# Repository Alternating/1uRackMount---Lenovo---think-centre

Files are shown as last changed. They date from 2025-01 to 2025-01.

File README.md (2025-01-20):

# 1uRackMount - m720q - any tiny think centre

This is a 1U rackmount for Lenovo Tiny USFF computers (specifically m720q). 
- Modded for the use with sliding rails

Original creator - https://www.thingiverse.com/thing:4769452

Hardware Required
- https://www.cigarhumidors-online.com/cigar-accessories/miscellaneous-smoking-accessories/1u-sliding-server-rack-shelf.html <-- buy to acquire sliding rails
- m4 heat serts - 4mm x 4mm L x 6mm OD
- m3 heat serts - 3mm x 4mm L x 5mm OD
- m4 x 6mm - [Flathead socket cap]
- m3 [Flange lock nuts] 
- m3 x 0.5mm [hex nuts]
- m3 x 8mm [button head]
- m3 x 20mm [socket head]
- m4 x 20mm [button head]
- m4 x 10mm [socket head]
- m4 x 30mm [socket head]
- m4 x 50mm [button head]

Hardware Locations->: 

- 4x m4 [heatserts] - |-> Front
- 4x m4 30mm [socket head] - |-> Front
- 2x m4 [heatserts] - |-> Right Side
- 2x m4 6mm [FlatHead SocketCap] - |-> Right Side
- 2x m4 [heatserts] - |-> Left Side
- 2x m4 6mm [FlatHead SocketCap] - |-> Left Side
- 4x m3 20mm [sockethead] - |-> Rear Cap
- 3x m3 8mm [button head] - |-> connect left/right with extension
- 6x m3 [Flange lock nuts] - |-> connect left/right with extension
- 2x m3 8mm [button head] - |-> connect left/right with extension
- 2x m3 [hexnut] - |-> connect left/right with extension

- HDD: 8x m3 8mm [button head]

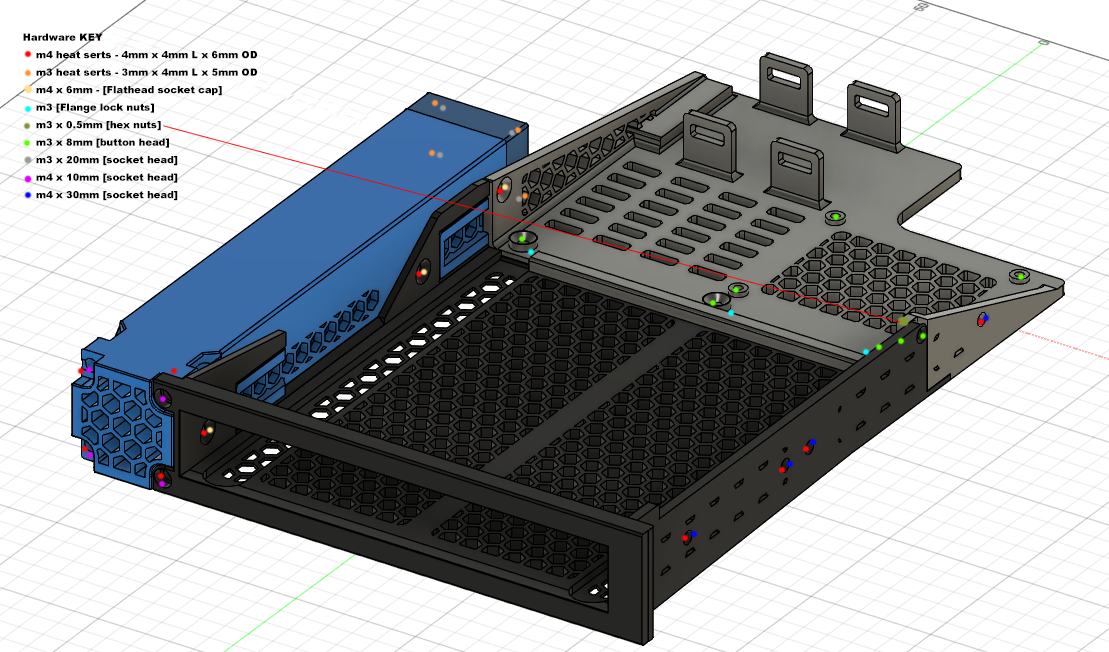
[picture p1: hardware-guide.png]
Hardware Guide 1U Rack Mount Hardware Guide


Modified Assembly: *** update required ****

1. Use a long M4 screw and pre-thread the center cap if using.
2. Use a long M4 screw and pre-thread the center rear holes.
3. Screw the center and center cap (or fan) together.
4. If using steel rack ears, insert nuts into slots and screw ears to brackets
5. Insert nuts into all hex shaped spots on the bracket and extensions.
6. Pick a side to start.  Place nuts into hex shaped notches in the center piece.
7. Slide in the bracket.  Screw bracket in place.
8. Repeat steps 2 and 3 for the other side.
9. Slide extension on top of bracket so that all holes are aligned.  Screw together bracket and extension.
10. Place screw through extension and center and tighten.

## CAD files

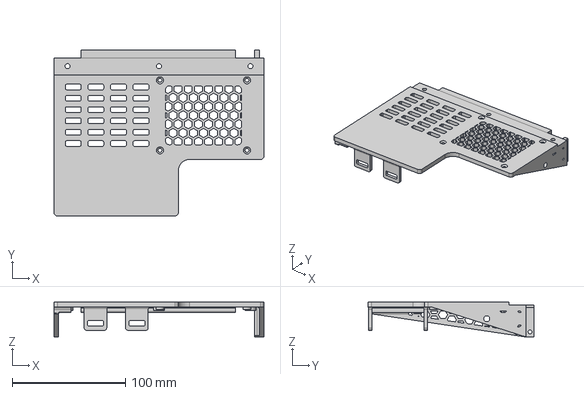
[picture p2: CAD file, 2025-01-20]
Printable Parts/Right Extension.step
185.8 x 146.8 x 30.9 mm

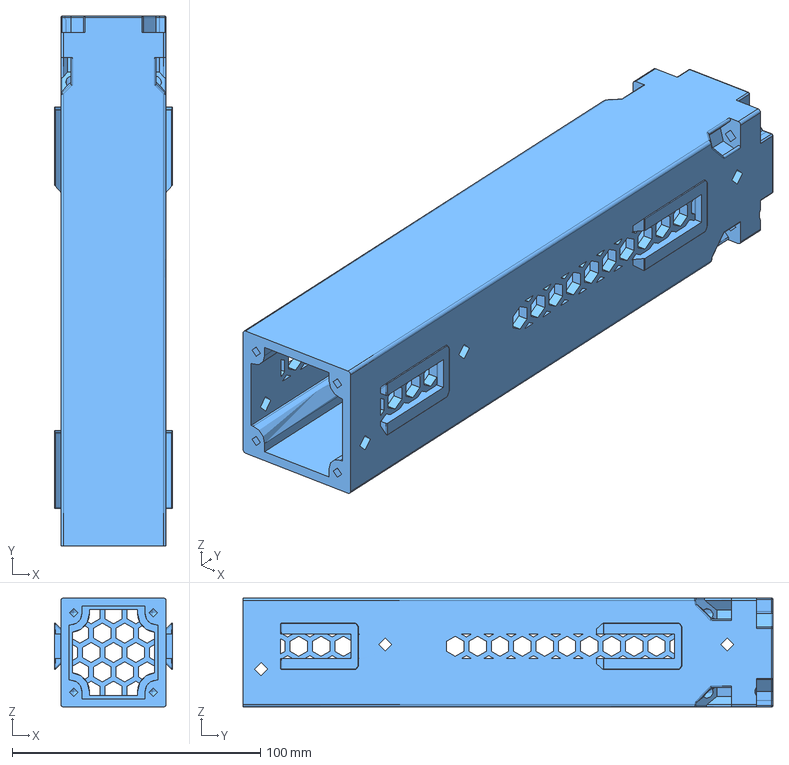
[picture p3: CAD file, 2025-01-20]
Printable Parts/Center.step
47.5 x 213.3 x 43.8 mm

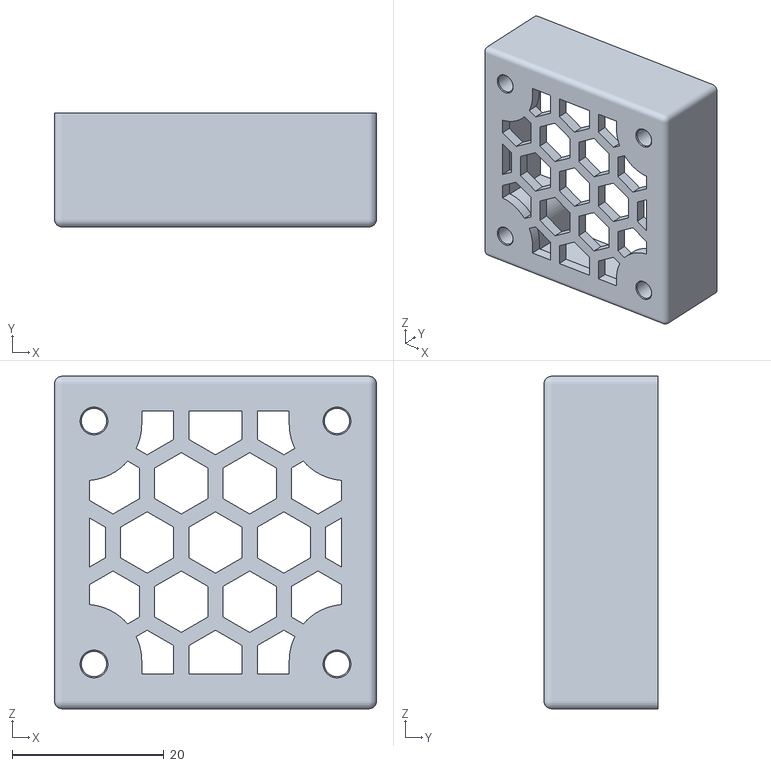
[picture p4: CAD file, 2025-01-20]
Printable Parts/Lenovo_Mount_-_Center_Cap.stl
42.4 x 15.0 x 43.8

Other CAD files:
Printable Parts/left Extension.step

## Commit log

2025-01-20 Files to print for remix
    [Center.step, Lenovo_Mount_-_Center_Cap.stl, Right Extension.step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]
2025-01-20 Main CAD File
